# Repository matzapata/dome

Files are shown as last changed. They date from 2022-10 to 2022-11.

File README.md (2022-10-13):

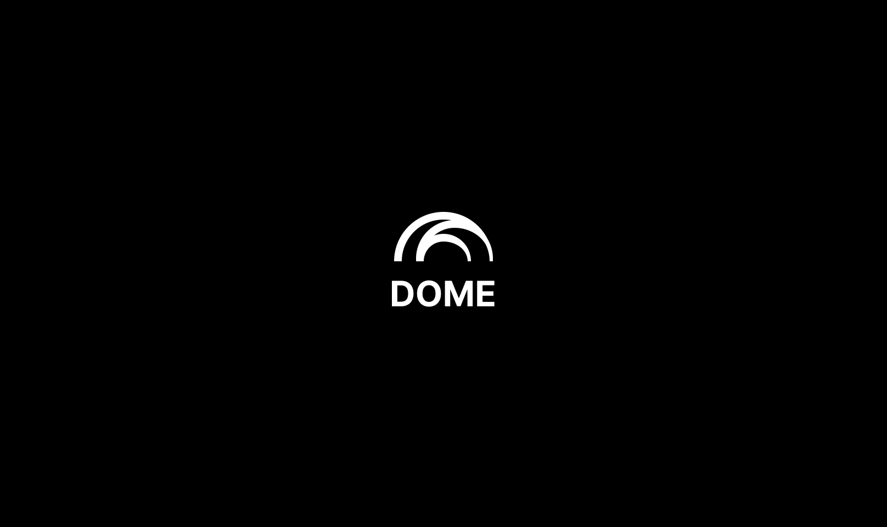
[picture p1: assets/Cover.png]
Cover


# DOME IOT

IOT modular system to control electrical connections over Wi-Fi.
The projects consists of:
- Modular hardware built with Esp8266 and programmed with C++ that will be placed in electrical sockets
- Phone application built with React Native and expo to connect devices, control them and add family members to it. 

The figma designs are already built and can be found here: 
-  https://www.figma.com/file/vcR1ODs3bJzUiS0fuz7EVW/DOME?node-id=1102%3A9203

## Device setup

1. Create `dome-device/Secrets.h` and fill with firebase credentials

```
#define FIREBASE_HOST "..."
#define FIREBASE_RTDB_SECRET "..." 
```

2. Upload code

3. Make electrical connections and power device on

4. Reset device and keep setup button pressed

5. Connect to "DOME" network initiated by device

6. Make a `POST` to `http://192.168.4.1/set` with `ssid`, `pass`, `home_id` and `device_id` on the body of the request.

```curl
curl --location --request POST 'http://192.168.4.1/set' \
--header 'Content-Type: application/json' \
--data-raw '{
    "ssid": "...",
    "pass": "...",
    "home_id": "...",
    "device_id": "..."
}'
```

If everything is ok, device will respond with `200 "OK"`

7. That's all. Reconect your phone to your wifi and interact with the device

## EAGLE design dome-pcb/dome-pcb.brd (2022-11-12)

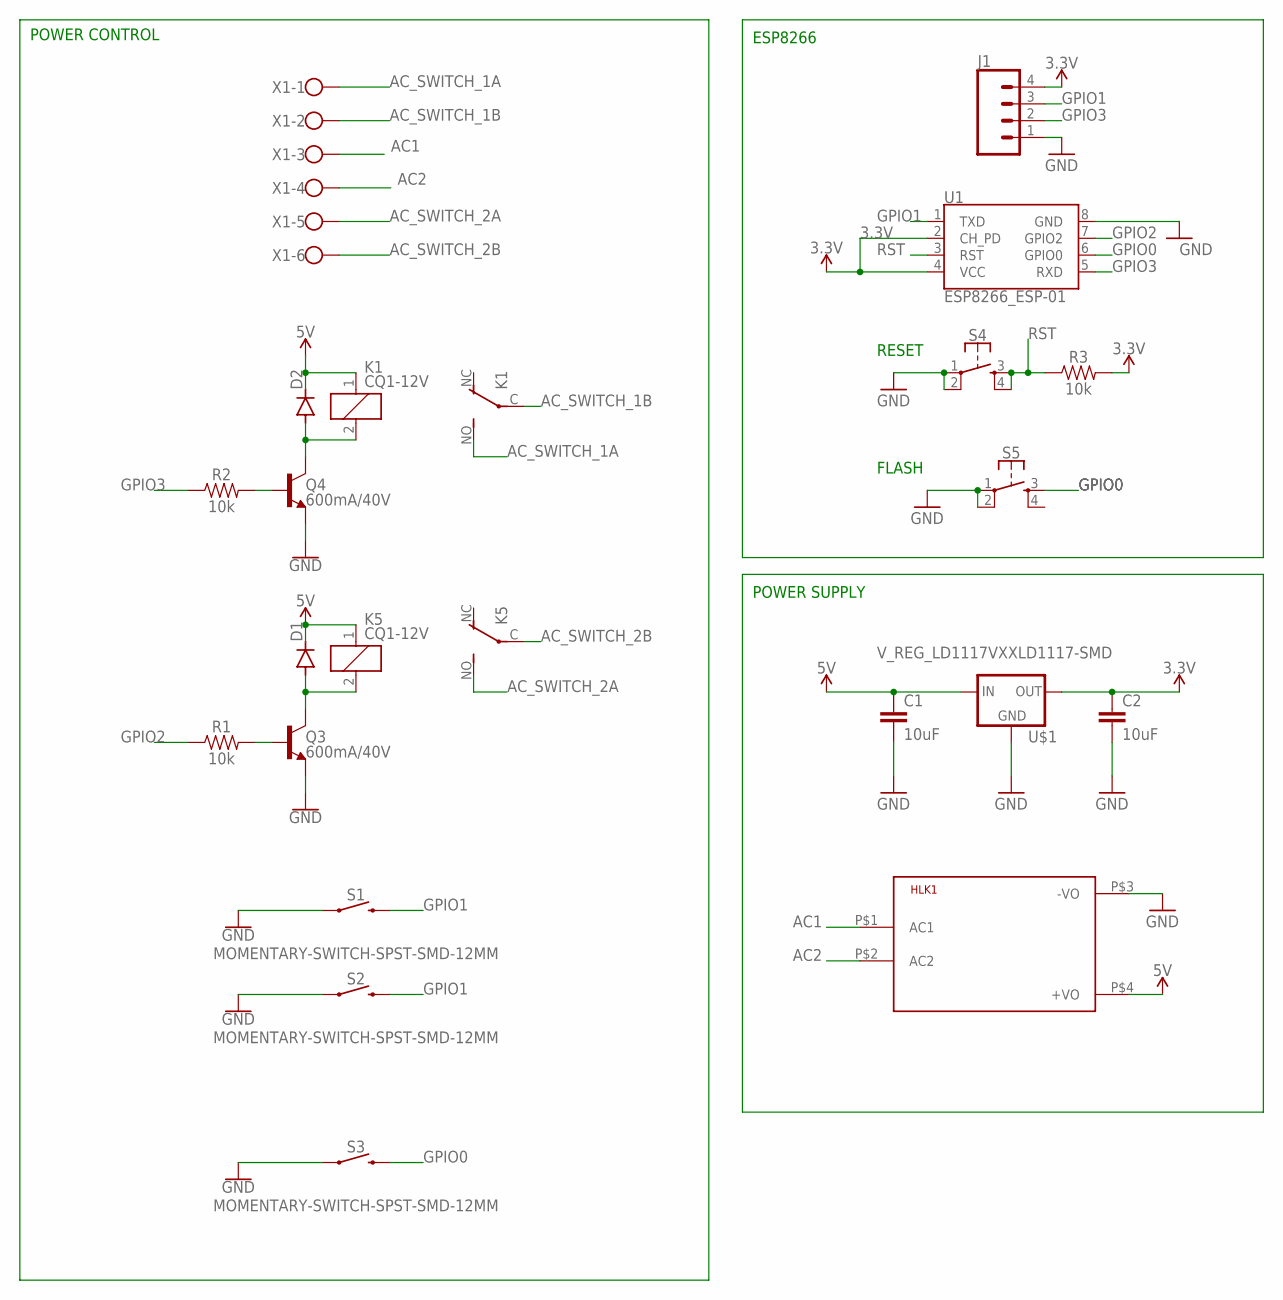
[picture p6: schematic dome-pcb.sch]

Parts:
C1, C2: 10uF; 0603
D1, D2: DIODE-DO-214AC; DO-214AC
HLK1: HLK-PM013W; HLK-PM01
J1: CONN_04PTH; 1X04
K1, K5: CQ1-12V; CQ1
Q3, Q4: 600mA/40V; SOT23-3
R1, R2, R3: 10k; 0603
S1, S2, S3: MOMENTARY-SWITCH-SPST-SMD-12MM; TACTILE_SWITCH_SMD_12MM
S4, S5: MOMENTARY-SWITCH-SPST-2-SMD-5.2MM; TACTILE_SWITCH_SMD_5.2MM
U1: ESP8266_ESP-01
U$1: V_REG_LD1117VXXLD1117-SMD; SOT223
X1: W237-6

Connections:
3.3V: C2.1, J1.4, R3.2, U1.2 (CH_PD), U1.4 (VCC), U$1.2 (OUT)
5V: C1.1, D1.C, D2.C, HLK1.P$4 (+VO), K1.1, K5.1, U$1.3 (IN)
AC1: HLK1.P$1 (AC1), X1.3
AC2: HLK1.P$2 (AC2), X1.4
AC_SWITCH_1A: K1.NO (S), X1.1
AC_SWITCH_1B: K1.C, X1.2
AC_SWITCH_2A: K5.NO (S), X1.5
AC_SWITCH_2B: K5.C, X1.6
GND: C1.2, C2.2, HLK1.P$3 (-VO), J1.1, Q3.2 (E), Q4.2 (E), S1.1, S2.1, S3.1, S4.1, S4.2, S5.1, S5.2, U1.8 (GND), U$1.1 (GND)
GPIO0: S3.3 (2), S5.3, U1.6 (GPIO0)
GPIO1: J1.3, S1.3 (2), S2.3 (2), U1.1 (TXD)
GPIO2: R1.1, U1.7 (GPIO2)
GPIO3: J1.2, R2.1, U1.5 (RXD)
unnamed: D2.A, K1.2, Q4.3 (C)
unnamed: Q4.1 (B), R2.2
unnamed: D1.A, K5.2, Q3.3 (C)
unnamed: Q3.1 (B), R1.2
RST: R3.1, S4.3, S4.4, U1.3 (RST)

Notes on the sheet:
FLASH
RESET
POWER CONTROL
ESP8266
POWER SUPPLY

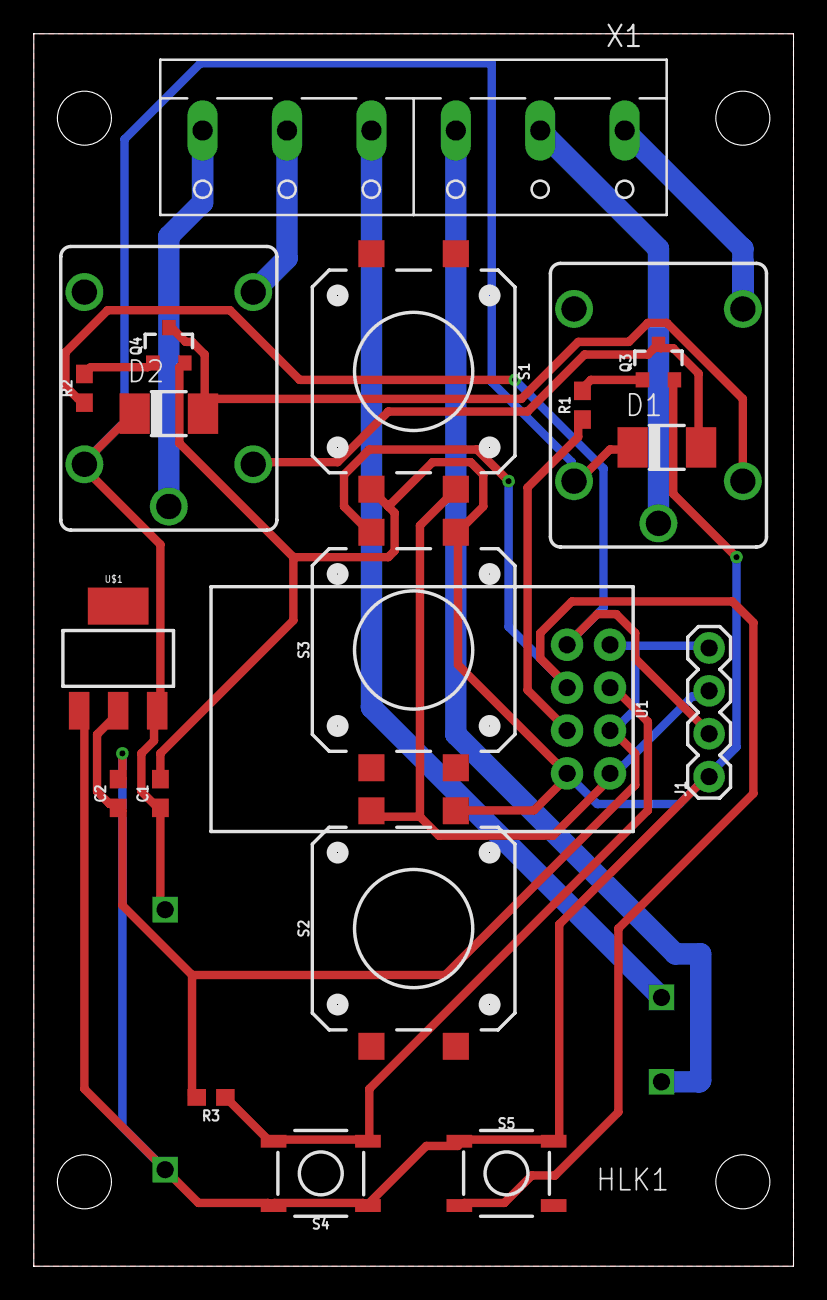
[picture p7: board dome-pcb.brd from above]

Board: 2 copper layers, 45.0 x 73.0 mm, 21 parts (0 on the bottom side), 18 nets.

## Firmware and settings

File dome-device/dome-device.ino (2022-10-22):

/*************************************************************************************************
 **                                          INCLUDES
 *************************************************************************************************/
#include "Secrets.h"
#include <Firebase_ESP_Client.h> // 4.1.0
#include <addons/TokenHelper.h>
#include <addons/RTDBHelper.h>
#include "ConnectionManager.h"
#include "Config.h"

/*************************************************************************************************
 **                                          DEFINES
 *************************************************************************************************/
#define NODE0_BTN D1
#define NODE1_BTN D2
#define NODE2_BTN D4
#define NODE0_PIN D6
#define NODE1_PIN D7
#define NODE2_PIN D8
#define CONFIG_BTN NODE0_BTN

/*************************************************************************************************
 **                                      GLOBAL VARIABLES
 *************************************************************************************************/
FirebaseData fbdo;
FirebaseAuth auth;
FirebaseConfig config;
FirebaseData stream0;
FirebaseData stream1;
FirebaseData stream2;

char pathBuffer[100];
bool nodeStates[3] = { false };
short nodePinMapout[3] = { NODE0_PIN, NODE1_PIN, NODE2_PIN };
short nodeBtnMapout[3] = { NODE0_BTN, NODE1_BTN, NODE2_BTN };
volatile bool nodeDataChanged[3] = { false };

/*************************************************************************************************
 **                                    MACROS
 *************************************************************************************************/
#define BEGIN_NODE_FB_STREAM(NODE, NODE_STR) \
  sprintf(pathBuffer, "/domes/%s/devices/%s/switches/" NODE_STR "/state", homeId, deviceId); \
  Serial.printf("Listening on: %s\n", pathBuffer); \
  if (!Firebase.RTDB.beginStream(&stream##NODE, pathBuffer)) { \
    Serial.printf("stream begin error, %s\n\n", stream##NODE.errorReason().c_str()); \
  } \
  Firebase.RTDB.setStreamCallback(&stream##NODE, streamCallback##NODE, streamTimeoutCallback##NODE);

#define STREAM_CALLBACK(NODE) \
  void streamCallback##NODE(FirebaseStream data) { \
    printResult(data); \
    Serial.printf("Received stream payload size: %d (Max. %d)\n\n", data.payloadLength(), data.maxPayloadLength()); \
    nodeDataChanged[NODE] = true; \
  }

#define STREAM_TIMEOUT_CALLBACK(NODE) \
  void streamTimeoutCallback##NODE(bool timeout) { \
    if (timeout) \
      Serial.println("stream timed out, resuming...\n"); \
    if (!stream##NODE.httpConnected()) \
      Serial.printf("error code: %d, reason: %s\n\n", stream##NODE.httpCode(), stream##NODE.errorReason().c_str()); \
  }

#define SYNC_NODE(NODE, NODE_STR) \
  if (Firebase.ready()) { \
    if (digitalRead(nodeBtnMapout[NODE])) { \
      nodeStates[NODE] = !nodeStates[NODE]; \
      sprintf(pathBuffer, "/domes/%s/devices/%s/switches/" NODE_STR "/state", homeId, deviceId); \
      Serial.printf("Update state: %s\n", pathBuffer); \
      Firebase.RTDB.setBool(&fbdo, pathBuffer, (bool)nodeStates[NODE]); \
      delay(200); \
    } \
  } \
  if (nodeDataChanged[NODE]) { \
    nodeDataChanged[NODE] = false; \
    if (stream##NODE.dataTypeEnum() == fb_esp_rtdb_data_type_boolean) { \
      bool state = stream##NODE.boolData(); \
      nodeStates[NODE] = state; \
      Serial.print("NODE: "); \
      Serial.print(NODE); \
      Serial.print("STATE: "); \
      Serial.println(state); \
    } \
  }

/*************************************************************************************************
 **                                    FUNCTION PROTOTYPES
 *************************************************************************************************/


/*************************************************************************************************
 **                                    FUNCTIONS IMPLEMENTATIONS
 *************************************************************************************************/
STREAM_TIMEOUT_CALLBACK(0)
STREAM_CALLBACK(0)
STREAM_TIMEOUT_CALLBACK(1)
STREAM_CALLBACK(1)
STREAM_TIMEOUT_CALLBACK(2)
STREAM_CALLBACK(2)

/*************************************************************************************************
 **                                          MAIN
 *************************************************************************************************/

void setup() {
  Serial.begin(115200);

  pinMode(NODE0_BTN, INPUT);
  pinMode(NODE1_BTN, INPUT);
  pinMode(NODE2_BTN, INPUT);
  pinMode(NODE0_PIN, OUTPUT);
  pinMode(NODE1_PIN, OUTPUT);
  pinMode(NODE2_PIN, OUTPUT);

  // Initiate wifi access point if no credentials stored or connect to wifi
  connectionBegin(CONFIG_BTN);

  // Initiate fb connection
  config.api_key = API_KEY;
  auth.user.email = USER_EMAIL;
  auth.user.password = USER_PASSWORD;
  config.database_url = DATABASE_URL;
  config.token_status_callback = tokenStatusCallback;
  Firebase.begin(&config, &auth);
  Firebase.reconnectWiFi(true);

  BEGIN_NODE_FB_STREAM(0, "0")
  BEGIN_NODE_FB_STREAM(1, "1")
  BEGIN_NODE_FB_STREAM(2, "2")
}

void loop() {
  SYNC_NODE(0, "0")
  SYNC_NODE(1, "1")
  SYNC_NODE(2, "2")

  digitalWrite(NODE0_PIN, nodeStates[0]);
  digitalWrite(NODE1_PIN, nodeStates[1]);
  digitalWrite(NODE2_PIN, nodeStates[2]);
}

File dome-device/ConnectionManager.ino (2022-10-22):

/*************************************************************************************************
 **                                          INCLUDES
 *************************************************************************************************/
#include <ESP8266WiFi.h>
#include <ESP8266WebServer.h>
#include <EEPROM.h>
#include "Config.h"
#include "Secrets.h"
#include "ConnectionManager.h"
#include <ArduinoJson.h>  // @5.13.5

/*************************************************************************************************
 **                                          DEFINES
 *************************************************************************************************/
#define SSID_ADDR 0
#define PASS_ADDR 50
#define HOME_ID_ADDR 100
#define DEVICE_ID_ADDR 150


/*************************************************************************************************
 **                                      GLOBAL VARIABLES
 *************************************************************************************************/
ESP8266WebServer server(80);

#if DEBUG
char ssid[EEPROM_BLOCK_SIZE] = { DEBUG_SSID };
char pass[EEPROM_BLOCK_SIZE] = { DEBUG_PASS };
char homeId[EEPROM_BLOCK_SIZE] = { DEBUG_HOME_ID };
char deviceId[EEPROM_BLOCK_SIZE] = { DEBUG_DEVICE_ID };
#else
char ssid[EEPROM_BLOCK_SIZE];
char pass[EEPROM_BLOCK_SIZE];
char homeId[EEPROM_BLOCK_SIZE];
char deviceId[EEPROM_BLOCK_SIZE];
#endif

/*************************************************************************************************
 **                                   PRIVATE FUNCTIONS PROTOTYPES
 *************************************************************************************************/
void getConfig();
void setConfig();
void writeEepromString(int addr, String data);
String readEepromString(int addr);
void scanNetworks();
void serverSendOk();
void connectionMode();
void configurationMode();

/*************************************************************************************************
 **                                   PUBLIC FUNCTIONS IMPLEMENTATIONS
 *************************************************************************************************/
void connectionBegin(short configBtn) {
    EEPROM.begin(512);
#if !DEBUG
  if (digitalRead()) {
    Serial.println("Config mode");
    configurationMode();
  }
  getConfig();
#endif
  connectionMode();
}

/*************************************************************************************************
 **                                   PRIVATE FUNCTIONS IMPLEMENTATIONS
 *************************************************************************************************/ 
void getConfig() {
  readEepromString(SSID_ADDR).toCharArray(ssid, EEPROM_BLOCK_SIZE);
  readEepromString(PASS_ADDR).toCharArray(pass, EEPROM_BLOCK_SIZE);
  readEepromString(HOME_ID_ADDR).toCharArray(homeId, EEPROM_BLOCK_SIZE);
  readEepromString(DEVICE_ID_ADDR).toCharArray(deviceId, EEPROM_BLOCK_SIZE);

  Serial.println(ssid);
  Serial.println(pass);
  Serial.println(homeId);
  Serial.println(deviceId);
}

void setConfig() {
  String data = server.arg("plain");
  StaticJsonBuffer<200> jBuffer;
  JsonObject& jObject = jBuffer.parseObject(data);
  String ssid = jObject["ssid"];
  String pass = jObject["pass"];
  String home_id = jObject["home_id"];
  String device_id = jObject["device_id"];

  writeEepromString(SSID_ADDR, ssid);
  writeEepromString(PASS_ADDR, pass);
  writeEepromString(HOME_ID_ADDR, home_id);
  writeEepromString(DEVICE_ID_ADDR, device_id);

  serverSendOk();
}

void writeEepromString(int addr, String data) {
  int size = data.length();
  char inchar[50];
  data.toCharArray(inchar, size + 1);

  for (int i = 0; i < size; i++) {
    EEPROM.write(addr + i, inchar[i]);
  }
  for (int i = size; i < 50; i++) {
    EEPROM.write(addr + i, 255);
  }

  EEPROM.commit();
}

String readEepromString(int addr) {
  byte readByte;
  String retVal;

  for (int i = addr; i < addr + 50; i++) {
    readByte = EEPROM.read(i);
    if (readByte != 255) {
      retVal += (char)readByte;
    }
  }

  return retVal;
}

void scanNetworks() {
  short scannedNetworks = WiFi.scanNetworks();

  if (scannedNetworks == 0) {
    Serial.println("No networks found");
    server.send(404, "text/json", "{\"networks\": []}");
  } else {
    Serial.print(scannedNetworks);
    Serial.println(" networks found");
    String networksJson = "{\"networks\": [";

    for (int i = 0; i < scannedNetworks; ++i) {
      // Add networks to message
      // WiFi.encryptionType 5:WEP 2:WPA/PSK 4:WPA2/PSK 7:open network 8:WPA/WPA2/PSK
      networksJson += "\"" + String(i + 1) + ": " + WiFi.SSID(i) + " (" + WiFi.RSSI(i) + ") Ch: " + WiFi.channel(i) + " Enc: " + WiFi.encryptionType(i) + "\"";
      if (i < scannedNetworks) {
        networksJson += ",";
      }
      delay(10);
    }

    networksJson += "]}";
    Serial.println(networksJson);
    server.send(200, "text/json", networksJson);
  }
}

void serverSendOk() {
  server.sendHeader("Connection", "close");
  server.sendHeader("Access-Control-Allow-Origin", "*");
  server.send(200, "text/plain", "OK\r\n");
}

void connectionMode() {
  short connectionAttemps = 0;

  WiFi.mode(WIFI_STA);
  WiFi.begin(ssid, pass);

  while (WiFi.status() != WL_CONNECTED && connectionAttemps < 50) {
    connectionAttemps++;
    Serial.println(".");
    delay(250);
  }
  if (connectionAttemps < 50) {
    Serial.println("WiFi connected");
    Serial.println(WiFi.localIP());
  } else {
    Serial.println("Error in connection");
    while (true) {}
  }
}

void configurationMode() {
  WiFi.softAP(ACCESS_POINT_SSID, ACCESS_POINT_PASS);

  Serial.print("Access point ip: ");
  Serial.println(WiFi.softAPIP());

  server.on("/", serverSendOk);
  server.on("/set", setConfig);
  server.on("/scan", scanNetworks);
  server.begin();

  while (true) {
    server.handleClient();
  }
}

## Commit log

2022-10-13 Firebase RTDB and buttons integration
2022-10-15 Switch Card
2022-10-15 Switches home rendering
2022-10-17 Setup device screens UI
2022-10-18 Firebase redux connection. Bug in device switch
2022-10-18 DeviceSwitch with rtdb sync
2022-10-18 Refactor device and fix status bar
2022-10-18 Remove google auth buttons
2022-10-22 Device code modularization ConnectionManager
2022-10-22 Altium project creation
    [DOME.PrjPcb, DOME_Pcb.PcbDoc, DOME_Pcblib.PcbLib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]
2022-11-12 PCB v1 with ESP8266 and non SMD components
    [DOME.PrjPcb, DOME_Pcb.PcbDoc, DOME_Pcblib.PcbLib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]
2022-11-12 Update PCB design with SMD components and a better layout
    [dome-pcb.brd, dome-pcb.sch]
2022-11-12 PCB Schematics and board
    [dome-pcb.brd, dome-pcb.sch]

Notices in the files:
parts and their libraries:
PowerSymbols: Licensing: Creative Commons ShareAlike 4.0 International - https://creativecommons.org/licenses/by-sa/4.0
